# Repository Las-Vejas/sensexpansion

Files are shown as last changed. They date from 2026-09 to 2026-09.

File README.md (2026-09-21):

# sensexpansion

This is an expansion module for the [Hackxpansion console](https://github.com/hackclub/hackxpansion). This module provides the console with different information like temperature, humidity, rotation, and others.
The module consists of the **BME280** temperature and humidity sensor and the **LIS3DH** accelerometer.

<p align="center">
  Main screen
</p>

<p align="center">
  
  
</p>

<p align="center">
  
  
</p>

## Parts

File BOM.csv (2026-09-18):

Reference | Price | Qty | Value | LCSC Part #
C1,C2 | 0.50 $US | 2 | 100nf | C60474
D1 | 0.69 $US | 1 | LED | C20608782
J1 | 0.00 $US | 1 | N/A | N/A
R1 | 0.13 $US | 1 | 22k | C140179
R2 | 0.15 $US | 1 | 1k | C140197
R3 | 0.21 $US | 1 | 300 | C25102
R4,R5 | 0.14 $US | 2 | 4.7k | C140158
U1 | 1.88 $US | 1 | LIS3DH | C15134
U2 | 7.13 $US | 1 | BME280 | C92489
PCB | 4.00 $US | 5 | N/A | N/A
Stencil | 3.07 $US | 1 | N/A | N/A
TOTAL | 17.90 $US |  | N/A | N/A

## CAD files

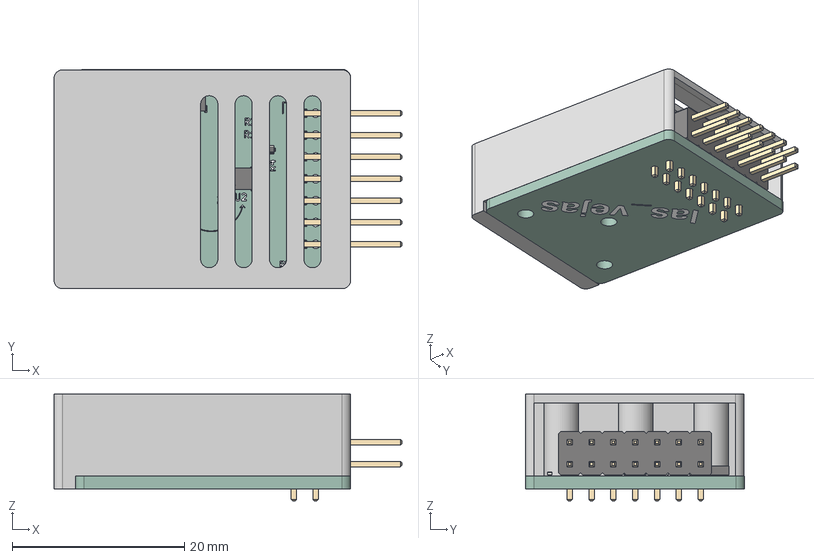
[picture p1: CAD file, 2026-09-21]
3d/sensexpansionASSEMBLY.step
40.5 x 25.5 x 12.4 mm
LGA_16_3x3mm_P05mm_LayoutBorder3x5y
R_0402_1005Metric_1 x 5
C_0402_1005Metric_1 x 2
Bosch_LGA_8_25x25mm_P065mm_ClockwisePinNumbering
PinHeader_2x07_P254mm_Horizontal
LED_0402_1005Metric_1
Sensexpansion_silkscreen
Sensexpansion_silkscreen_1
Sensexpansion_PCB

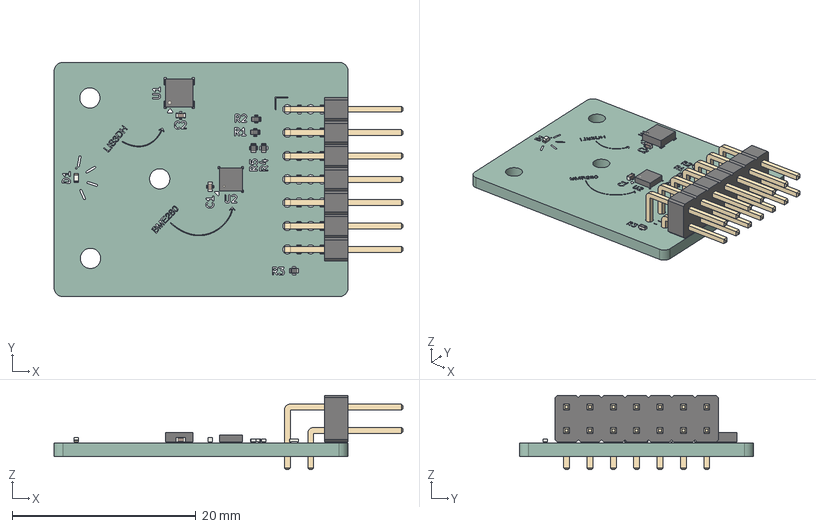
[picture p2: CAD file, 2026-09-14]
3d/sensexpansionPCB.step
38.0 x 25.5 x 8.08 mm
LGA_16_3x3mm_P05mm_LayoutBorder3x5y
R_0402_1005Metric x 5
C_0402_1005Metric x 2
Bosch_LGA_8_25x25mm_P065mm_ClockwisePinNumbering
PinHeader_2x07_P254mm_Horizontal
LED_0402_1005Metric
Sensexpansion_silkscreen x 2
Sensexpansion_PCB

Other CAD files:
3d/sensexpansion_case.f3d

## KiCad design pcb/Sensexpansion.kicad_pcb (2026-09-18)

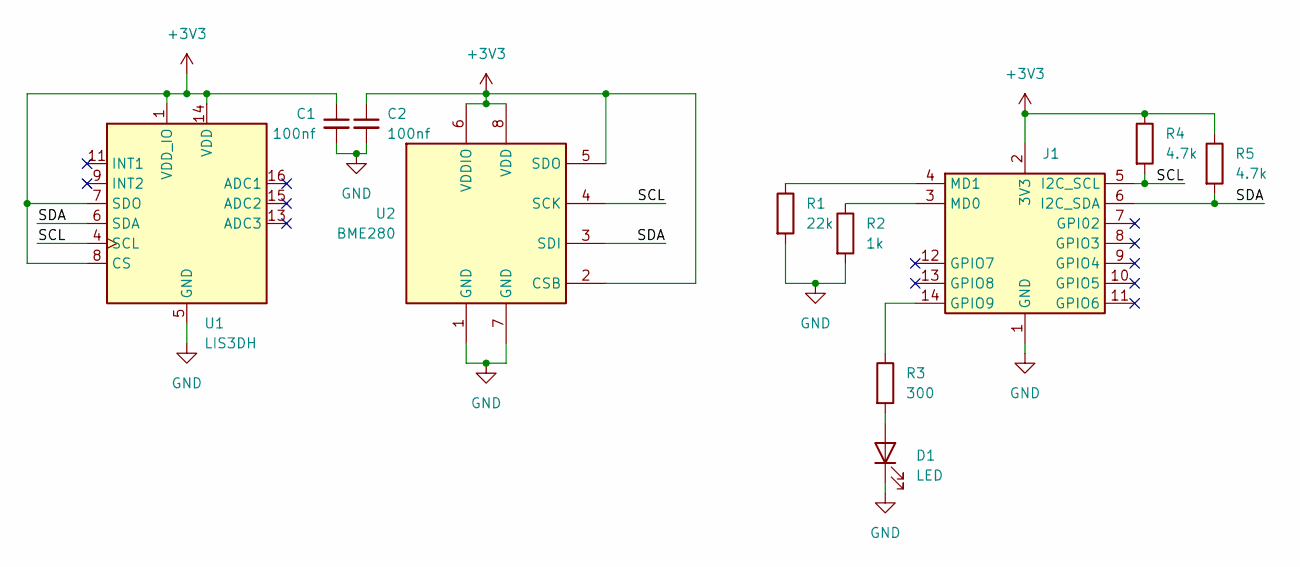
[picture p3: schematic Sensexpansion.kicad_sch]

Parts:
C1, C2: 100nf; C_0402_1005Metric; LCSC Part # C60474
D1: LED; LED_0402_1005Metric; LCSC Part # C20608782
J1: Male_Module
R1: 22k; R_0402_1005Metric; LCSC Part # C140179
R2: 1k; R_0402_1005Metric; LCSC Part # C140197
R3: 300; R_0402_1005Metric; LCSC Part # C25102
R4, R5: 4.7k; R_0402_1005Metric; LCSC Part # C140158
U1: LIS3DH; LGA-16_3x3mm_P0.5mm_LayoutBorder3x5y; LCSC Part # C15134
U2: BME280; Bosch_LGA-8_2.5x2.5mm_P0.65mm_ClockwisePinNumbering; LCSC Part # C92489

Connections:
+3V3: C1.1, C2.1, J1.2 (3V3), R4.1, R5.1, U1.1 (VDD_IO), U1.7 (SDO), U1.8 (CS), U1.14 (VDD), U2.2 (CSB), U2.5 (SDO), U2.6 (VDDIO), U2.8 (VDD)
/SCL: J1.5 (I2C_SCL), R4.2, U1.4 (SCL), U2.4 (SCK)
/SDA: J1.6 (I2C_SDA), R5.2, U1.6 (SDA), U2.3 (SDI)
GND: C1.2, C2.2, D1.1 (K), J1.1 (GND), R1.2, R2.2, U1.5 (GND), U1.10 (GND), U1.12 (GND), U2.1 (GND), U2.7 (GND)
unnamed: D1.2 (A), R3.2
unnamed: J1.14 (GPIO9), R3.1
unnamed: J1.3 (MD0), R2.1
unnamed: J1.4 (MD1), R1.1

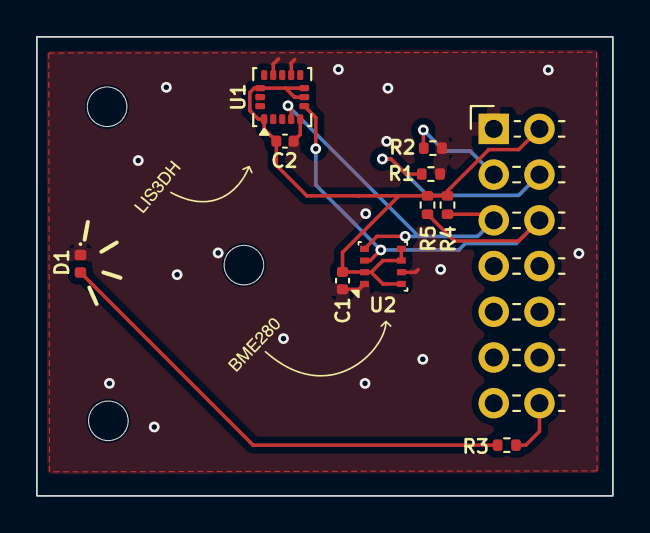
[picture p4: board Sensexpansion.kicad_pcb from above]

Board: 2 copper layers, 32.0 x 25.5 mm, 11 parts (0 on the bottom side), 8 nets.

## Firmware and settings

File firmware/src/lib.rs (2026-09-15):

#![no_std]

extern crate alloc;

use alloc::boxed::Box;
use alloc::sync::Arc;
use core::future::Future;
use core::pin::Pin;

use embassy_sync::blocking_mutex::raw::CriticalSectionRawMutex;
use embassy_sync::mutex::Mutex;
use xpanse_api::{
    bus::{
        allocator::BusAllocator,
        i2c::{I2cBusHandle, I2cError},
    },
    driver::{Driver, DriverError, DriverMeta},
    gpio_bank::{BankPins, GpioBank},
    interfaces::leds::{Generic, pin_led},
    metadata::{ModuleDetectResistor, ModuleID, ModuleSlot},
    reexports::embassy_time::Timer,
    registry::Registry,
};

/// Bit-banged I2C clock for the module bus.
const I2C_FREQUENCY_HZ: u32 = 100_000;

/// BME280 address with SDO tied to 3V3.
const BME280_ADDR: u8 = 0x77;
const BME280_CHIP_ID: u8 = 0xD0;
const BME280_CHIP_ID_VALUE: u8 = 0x60;
/// Temperature and pressure calibration, 0x88..=0xA1 (the last byte is dig_H1).
const BME280_CALIB_TP: u8 = 0x88;
/// Remaining humidity calibration, 0xE1..=0xE7.
const BME280_CALIB_H: u8 = 0xE1;
const BME280_CTRL_HUM: u8 = 0xF2;
const BME280_STATUS: u8 = 0xF3;
const BME280_CTRL_MEAS: u8 = 0xF4;
/// Pressure, temperature and humidity ADC values, 0xF7..=0xFE.
const BME280_DATA: u8 = 0xF7;
/// Humidity oversampling x1.
const BME280_CTRL_HUM_VALUE: u8 = 0b001;
/// Temperature and pressure oversampling x1 (osrs_t = osrs_p = 0b001), forced
/// mode (0b01, one conversion per write).
const BME280_CTRL_MEAS_FORCED: u8 = 0b0010_0101;
const BME280_STATUS_MEASURING: u8 = 0x08;
/// A x1/x1/x1 conversion takes under 10 ms, so 10 polls 2 ms apart is plenty.
const BME280_MAX_POLLS: u32 = 10;
const BME280_POLL_INTERVAL_MS: u64 = 2;

/// LIS3DH address with SDO/SA0 tied to 3V3.
const LIS3DH_ADDR: u8 = 0x19;
const LIS3DH_WHO_AM_I: u8 = 0x0F;
const LIS3DH_WHO_AM_I_VALUE: u8 = 0x33;
const LIS3DH_CTRL_REG1: u8 = 0x20;
const LIS3DH_CTRL_REG4: u8 = 0x23;
const LIS3DH_OUT_X_L: u8 = 0x28;
/// Setting the sub-address MSB makes the LIS3DH auto-increment on multi-byte reads.
const LIS3DH_AUTO_INCREMENT: u8 = 0x80;
/// 100 Hz output data rate, normal mode, X/Y/Z enabled.
const LIS3DH_CTRL_REG1_VALUE: u8 = 0x57;
/// Block data update, ±2 g full scale, high-resolution (12-bit) mode.
const LIS3DH_CTRL_REG4_VALUE: u8 = 0x88;
/// Sensitivity at ±2 g in high-resolution mode is 1 mg per digit.
const LIS3DH_G_PER_DIGIT: f32 = 0.001;

/// Error returned by the module's sensor capabilities.
#[derive(Debug, Clone, Copy, PartialEq, Eq)]
pub enum SensorError {
    /// I2C communication with the sensor failed.
    BusError,
    /// The sensor answered with an unexpected chip ID.
    NoDevice,
    /// The sensor did not finish a measurement in time.
    Timeout,
    /// The sensor returned data that could not be processed.
    InvalidData,
}

impl From<I2cError> for SensorError {
    fn from(_: I2cError) -> Self {
        SensorError::BusError
    }
}

/// One environmental measurement from the BME280.
#[derive(Debug, Clone, Copy, PartialEq)]
pub struct EnvReading {
    /// Temperature in degrees Celsius.
    pub temperature_c: f32,
    /// Relative humidity in percent.
    pub humidity_percent: f32,
    /// Barometric pressure in pascals.
    pub pressure_pa: f32,
}

/// Async interface for reading temperature, humidity and pressure.
///
/// Apps lease it from the registry as `Box<dyn EnvSensor>`.
pub trait EnvSensor: Send {
    /// Trigger a measurement and return the compensated result.
    fn read<'a>(&'a mut self)
    -> Pin<Box<dyn Future<Output = Result<EnvReading, SensorError>> + 'a>>;
}

/// Acceleration on each axis, in units of g.
#[derive(Debug, Clone, Copy, PartialEq)]
pub struct Acceleration {
    pub x: f32,
    pub y: f32,
    pub z: f32,
}

/// Async interface for reading 3-axis acceleration.
///
/// Apps lease it from the registry as `Box<dyn Accelerometer>`.
pub trait Accelerometer: Send {
    /// Return the most recent acceleration sample.
    fn read<'a>(&'a mut self)
    -> Pin<Box<dyn Future<Output = Result<Acceleration, SensorError>> + 'a>>;
}

/// One device's handle to the I2C bus shared by both sensors.
///
/// Every call holds the bus lock for the whole transfer, so the sensors can be
/// leased by different apps without their transfers interleaving.
struct SharedI2c(Arc<Mutex<CriticalSectionRawMutex, I2cBusHandle>>);

impl SharedI2c {
    async fn write(&self, address: u8, bytes: &[u8]) -> Result<(), I2cError> {
        self.0.lock().await.write(address, bytes).await
    }

    async fn read_regs(&self, address: u8, reg: u8, buf: &mut [u8]) -> Result<(), I2cError> {
        self.0.lock().await.write_read(address, &[reg], buf).await
    }

    async fn read_reg(&self, address: u8, reg: u8) -> Result<u8, I2cError> {
        let mut buf = [0u8; 1];
        self.read_regs(address, reg, &mut buf).await?;
        Ok(buf[0])
    }
}

/// Factory trimming parameters, named as in the BME280 datasheet.
struct Bme280Calibration {
    t1: u16,
    t2: i16,
    t3: i16,
    p1: u16,
    p2: i16,
    p3: i16,
    p4: i16,
    p5: i16,
    p6: i16,
    p7: i16,
    p8: i16,
    p9: i16,
    h1: u8,
    h2: i16,
    h3: u8,
    h4: i16,
    h5: i16,
    h6: i8,
}
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
